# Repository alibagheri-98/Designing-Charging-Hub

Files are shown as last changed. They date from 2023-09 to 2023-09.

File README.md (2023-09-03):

During my 3-month internship at Nabz Company, I was tasked with creating a charging hub essential for Nabz's product lines. The development of this charging hub involved several phases:

## Phase 1: Literature Review
I commenced by conducting an extensive literature review of the ISO 13485 standard, utilizing research sources such as Research Gate, Scopus, and Google Scholar to gain comprehensive insights.
<br>
Screenshot (4620)
## Phase 2: Transformer Design
In the second phase, I employed the "PI Express" software to design the transformer. Subsequently, I thoroughly evaluated my design to ensure its suitability for the project. This included creating a schematic diagram, as shown in following image:
<br>
Screenshot (4622)
<br>
<br>
and an Altium Designer schematic diagram, as displayed in the following picture:
<br>
Screenshot (4624)
<br>
Screenshot (4626)

## Phase 3: Experimentation
Upon moving to the experimentation phase, an unexpected issue arose when the TNY280PN IC became excessively hot and ultimately failed within a few minutes. In response, we devised the idea of implementing a heat sink. This modification yielded excellent results, allowing the production line to begin using the charging hub successfully.

## Note:
- The report of my internship is in the "Report" folder.
- The simulations are in the "Simulation" folder.
- I received a "V_G" (Very Good) grade for my internship.
- My university supervisor for this internship was Dr. Zolghadri
- As per Sharif University of Technology's guidelines, internship reports should be in Persian. If you are interested in learning more about this project but are not proficient in Persian, please don't hesitate to reach out to me. We can arrange a meeting, and I will be happy to explain the project to you. You can contact me at [bagheri9877@gmail.com](bagheri9877@gmail.com).

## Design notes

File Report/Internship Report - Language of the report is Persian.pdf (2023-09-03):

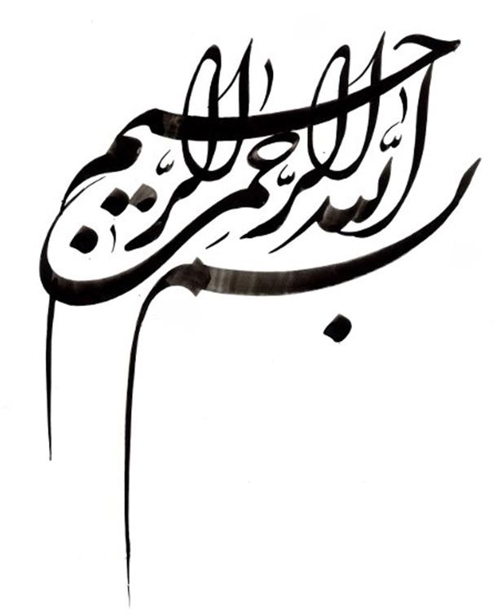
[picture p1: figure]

أ

أ

## دانشگاه صنعتی شریف

دانشکده مهندسی برق

گزارش کارآموزی
گرایش سیستم های انرژی الکتریکی

عنوان:

## گزارش کارآموزی در شرکت نبض هوشمند سالمت

نگارش :
علی باقری
96101302

استاد کارآموزی :
جناب آقای دکتر ذوالقدری

تاریخ)ماه و سال( : 1400/06

چکیده

تابستان سال 1400 فرصتی شد تا واحد کارآموزی را در شرکت نبض هوشمند سالمت به انجام برسانم.
در این گزارش ابتدا به معرفی شرکت و چگونگی سپری شدن این دوره 240 ساعته میپردازم و سپس پروژه واگذاری شده به من و فعالیت هایم را شرح میدهیم. در ابتدا در طی جلساتی توضیحات و روال کارآموزی داده شد و به تیم سازی پرداختیم. همچنین مدتی را به یادگیری کلیات کارآموزی پرداختیم. سپس به کارآموزان پروژه هایی واگذار شد که در این دوره روی آن پروژه ها کار کردند.

در پروژه ای که به ما واگذار شده بود، هدف طراحی یک هاب شارژر با ورودی برق شهر، و چهار خروجی USB بود. در ابتدا به مروری بر ادبیات پرداختیم و مقاالت مرتبط و منابع آموزشی علمی را به سرپرستی آقای محمد سعید دیاری بررسی کردیم. سپس یک طراحی اولیه انجام دادیم و بعد از شبیه سازی، به نمونه سازی رسیدیم. البته در فاز نمونه سازی مهلت کاراموزی تمام شد و پروژه در این مرحله تحویل شرکت گردید.

در فصل اول تاریخچه ای از شرکت را بیان میکنیم و در مورد فعالیت های صنعتی این شرکت توضیح میدهیم. سپس در فصل بعدی از فعالیت خودم در این دوره 240 ساعته میگوییم و در نهایت در فصل بعدی نتایج را بررسی میکنیم. امیدوارم این گزازش مورد قبول شما باشد.

توجه: شرکت نبض هوشمند سالمت، تاکید کرد که اطالعات گردآوری شده در این گزارش کارآموزی در جنبه های تجاری و رقابتی استفاده نگردد.

فهرست

1 فصل اول: آشنایی با شرکت نبض هوشمند سالمت 6 |
1-1 معرفی شرکت 6 |
1-2 چارت سازمانی شرکت 7 |
1-3 آینده شرکت نبض هوشمند سالمت 8 |

فهرست شکل ها

شکل :1-1 سه راهی تجاری برند تیراژه با دو درگاه USB | 10
شکل :2-1 شماتیک مدار ترانس | 11
شکل :3-1 برد طراحی شده شماتیک مدار ترانس | 12
شکل :4-1 برد طراحی شده شماتیک مدار ترانس | 13

### 1 فصل اول: آشنایی با شرکت نبض هوشمند سالمت

معرفی شرکت

گروه نبض در سال 1395 به صورت یک تیم کوچک فعالیت خود را در زمینه ی

ساخت تجهیزات توان بخشی شروع کرد. از تابستان سال 1396 توجه و تمرکز خود را به

زمینه تولید تجهیزات نوین پزشکی معطوف کرد. امروز فعالیت شرکت حول طراحی و تولید

ابزار ها و تجهیزات پیشرفته حوزه ی سالمت میگردد. هدف اصلی شرکت نبض هوشمند

سالمت، همراهی با مردم و پزشکان در راستای ارتقای سطح سالمت و گسترش خدمات

پزشکی است.

شرکت نبض هوشمند سالمت، با تولید ابزارها و گجتهای هوشمند حوزه سالمت در

تالش است تا از یک سو در کنار پزشکان و از سوی دیگر در کنار تمامی افرادی که به

سالمت جسمانی خود و عزیزانشان بها میدهند، قرار گیرد.

یکی از محورهای اصلی تفکرات شرکت نبض هوشمند سالمت، کمک گرفتن از

نیروهای جوان و با انگیزه در راستای استفاده از تکنولوژی و بهکارگیری خالقیت برای تولید

محصوالتی جدید است که نیازهایی واقعی را از مخاطب برطرف کنند. به دور از شعار، با

فعالیت ها و محصوالت خود طی سال های گذشته این شرکت سعی کرده است که نشان

دهد مصرانه به دنبال خلق دانش و ایجاد محصوالت با کیفیتی است تا مخاطب از کار کردن

با آن ها لذت ببرد.

از محورهای اصلی دیگر، امر تولید است؛ مسئلهای که شاید در شرایط کنونی کشور،

بسیاری از کارآفرینان بهناچار از آن فاصله گرفتهاند. مراحل طراحی محصول، فراهم آوردن

قطعات و ملزومات، مراحل تحقیق و توسعه، تست و عیبیابی و درنهایت اخذ تاییدیهها و

مجوزها و راهاندازی خط تولید از مواردی هستند که شاید به دلیل شرایط سختی که هرکدام

به همراه دارند، بسیاری را از ورود به مسیر تولید بازدارند. اما تمامی افراد حاضر در شرکت

نبض هوشمند سالمت، به دلیل ارزشی که در تولید هم برای سطح دانش و صنعت کشور و

هم برای چرخیدن چرخ اقتصاد و بهرهمند شدن تمام ایرانیان از برکات آن وجود دارد،

مصمم به ادامه این مسیر هستند و با وجود تمامی فشارها و سختیها، با امید فراوان به

آیندهای روشن تالش میکنند و از تمامی بازیگران این عرصه برای همکاری و توسعه این

مسیر در هر جایگاهی، استقبال میکنند.

چارت سازمانی شرکت

بخش مدیریت در باالترین سطح این شرکت قرار دارد و به سه قسمت -1تحقیق و

توسعه، -2نرم افزار و پلتفرم و -3 حقوقی و مالی تسلط دارد

واحد تحقیق و توسعه دارای زیر بخش های سخت افزار، واحد تولید، واحد کنترل

کیفیت است. همچنین واحد نرم افزار و پلتفرم دارای زیر بخش های نرم افزار، هوش

مصنوعی و یادگیری و پردازش سیگنال میباشد.

واحد حقوقی و مالی شامل بخش های فروش، پشتیبانی، مالی و حقوقی و انبار میباشد.

آینده شرکت نبض هوشمند سالمت

در حال حاضر و در شرایط فعلی که درگیر کرونا هستیم، شرکت نبض هوشمند سالمت

با رعایت کامل پروتکل های بهداشتی به فعالیت های خود ادامه میدهد تا برای عبور از این

شرایط سخت، تیم پزشکی را همراهی کند.

این شرکت در حال توسعه پروژه های سطح باال است تا در آینده شاهد توسعه گسترده

خویش باشد و همزمان با این مهم، یاری دهنده شرایط کشور در تحریم نیز باشد.

### 2 فصل دوم: یادگیری و پیاده سازی

مقدمه

موضوع دوره کاراموزی، طراحی و نمونه سازی یک دستگاه هاب شارژر بود که برای

خط تولید شرکت مورد نیاز است. بخشی از فرایند تولید و کنترل کیفی دستگاه های شرکت

نبض، شارژ باتری دستگاه هاست. با توجه به سیاست افزایش تیراژ تولید، نیاز به تعداد

بیشتری شارژر احساس شد بر همین مبنا، بجای خرید تعداد قابل توجهی شارژر، این راه

حل مطرح شد که صرفا کابل های شارژر خریداری شوند و جای قسمت به اصطالح آداپتور

شارژر، یک هاب طراحی شود که چندین خروجی داشته باشد.

از آنجایی که محصوالت شرکت دسته بندی های مختلفی دارند، تصمیم اولیه بر این

شد که هر هاب دو درگاه خروجی داشته باشد که دو درگاه آن 2 آمپر و 2 درگاه آن 1 آمپر

باشد. تعبیر فنی این اصطالح یعنی هر درگاه حداکثر تا چند آمپر را می تواند تامین کند.

مروری بر ادبیات

اولین موضوع مهم در پروژه های طراحی یک محصول، جمع آوری درست و علمی

دانش است. در این پروژه ما بر اساس استاندارد 13485ISO به مروری بر ادبیات پرداختیم.

بطور خالصه می توانیم بگوییم در سه مرحله کلی، مقاالت را غربال می کنیم. ابتدا در پایگاه

های داده مقاالت مانند gate Research ,Scopus ,scholar Google و سامانه های

داخلی مانند سیویلیکا، چند کلید واژه و عبارت مرتبط را انتخاب می کنیم و براساس نام

مقاالت آن ها را برمیگزینیم. سپس از بین مقاالت منتخب، براساس خالصه مقاالت تعدادی

دیگر را غربال می کنیم ودر نهایت به مطالعه متن کامل آن ها می پردازیم تا بتوانیم پارامترهای

موثر و سبک طراحی ادبیات رایج علمی در آن حوزه را کمی بشناسیم.

پس از پایان فاز مطالعه به یک نمونه مشابه تجاری )با قابلیت های کمتر( خریداری

کردیم و به مهندسی معکوس و استخراج نقشه فنی آن پرداختیم. محصول مذکور، یک سه

راهی تجاری برند تیراژه با دو درگاه USB است که در تصویر زیر آن را مشاهده می کنیم.

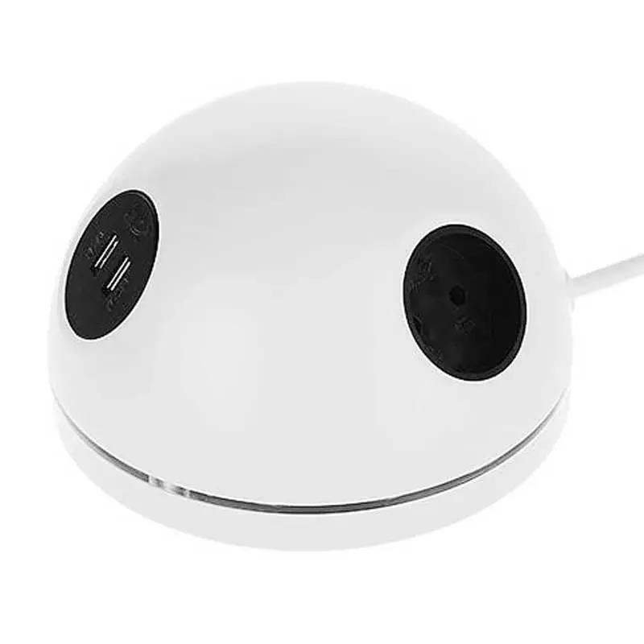
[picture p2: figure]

در فاز بعدی به طراحی ترانس توسط نرم افزار Express PI پرداختیم. نمونه ترانس

را برای ساخت سفارش دادیم و بر روی مدارهای آزمایشی )به اصطالح هزارسوراخ( مدرا

را امتحان کردیم.

شماتیک مدار طراحی شده را در شکل زیر می بینم:

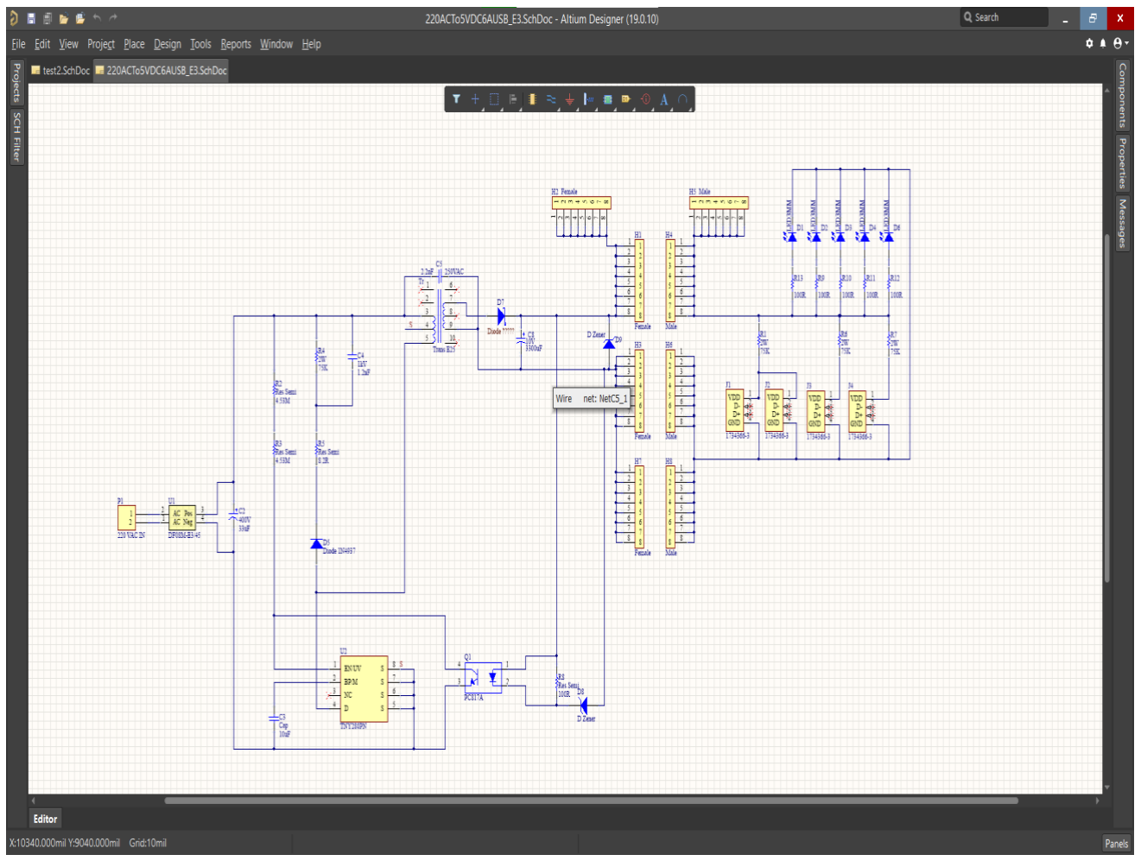
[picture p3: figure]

در آزمایش این مدار، آی سی PN280TNY بسیار داغ می شد و پس از چند دقیقه

کامال می سوخت. بخش قابل توجهی از زمان سپری شده، به رفع این عیب اختصاص داد

شد. پس از چند روز به این مورد احتمال داده شد که ترانس به اشتباه پیچیده شده باش و

مطابق با نقشه فنی مورد نظر ما نباشید. در حقیقت دراثر اشتباه سازنده، ترانس در مشخصات

درستی کار نکند. سفارش دوباره ترانس و مذاکره با ارائه دهنده خدمات پیچیدن ترانس، در

کنار زمان بر بودن این امر، بخش زیادی از زمان پروژه را طی کرد.

برای استفاده درست از زمان، به یادگیری طراحی PCB در نرم افزار Altium

Designer در این زمان پرداختیم. برد طراحی شده شماتیک باال را در تصویر زیر مشاهده

می کنیم:

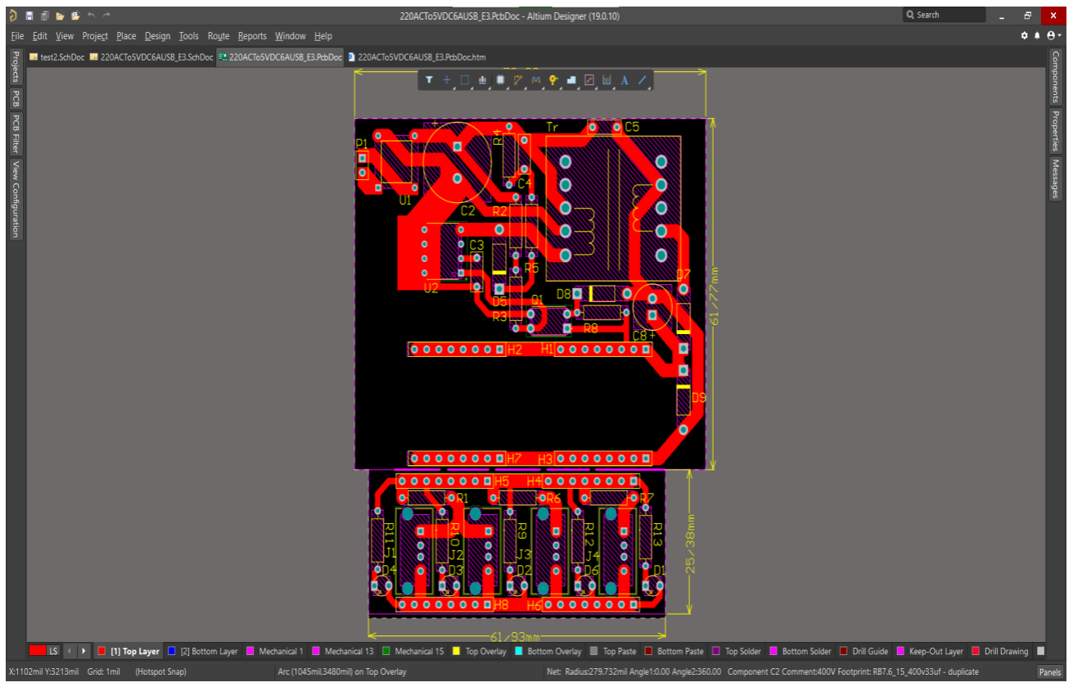
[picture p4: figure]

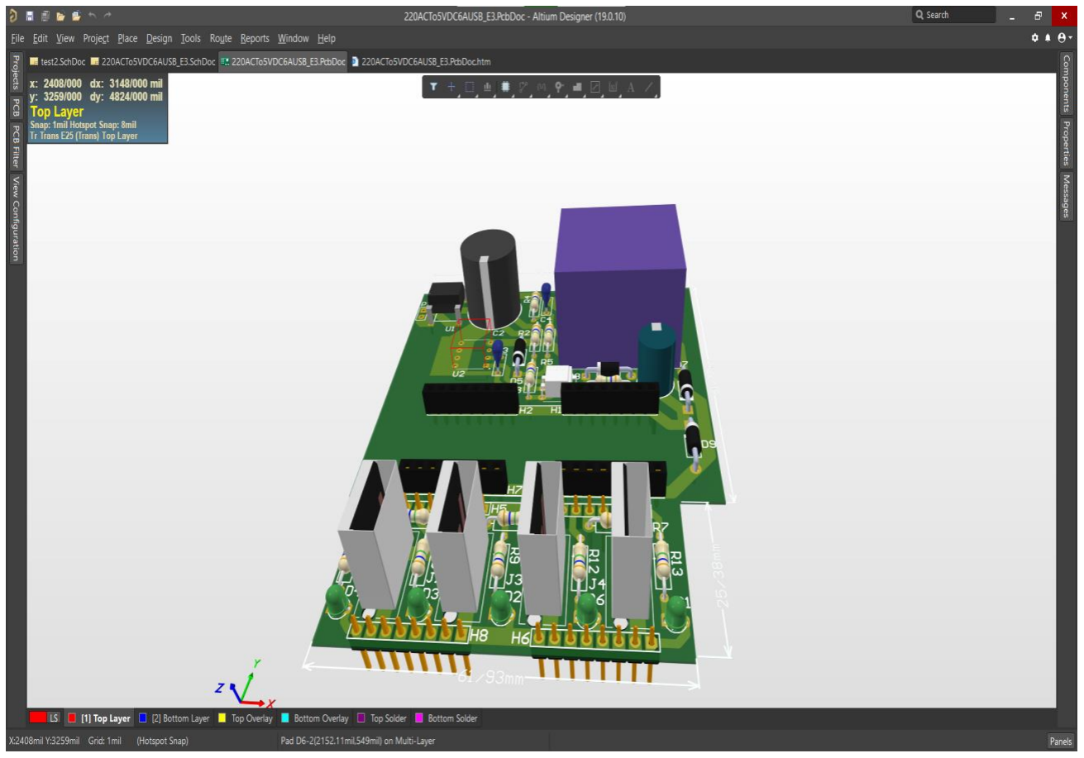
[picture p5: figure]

دراین طراحی، مالحظات جریان باال و حرارت در طراحی مدنظر قرار گرفته است.

پس از آزمایش مجدد متوجه شدیم مجددا در اثر اشتباه سازنده، ترانس را برای آی سی

های switch Top پیچیده اند و سازگار با آی سی های Switch Tiny نیست. بنابراین

مجددا پیگیر یک نمونه ترانس جدید شدیم.

اما در کمال تعجب پس از آزمایش ترانس جدید مشاهده کردیم که بازهم آی سی

PN280TNY داغ می شود و درنهایت پس از مدت کوتاه چند دقیقه ای می سوزد. در

نهایت پس از پرس و جو متوجه شدیم با استفاده از ابزارهای خنک کننده مانند Heat

Sink می توانیم دمای این آی سی را کنترل کنیم و مدار توانست در حالت پایدار خود

بماند.

متاسفانه بعلت زمان بر بودن فرایند هایی مانند پیچیدن ترانس، این پروژه تا همین نقطه

پیشرئی داشت و به پایان رساندن آن نیازمند زمان بیشتری ست.

### 3 فصل سوم: جمعبندی، نتیجهگیری و پیشنهادها

جمعبندی

بطور خالصه ما ابتدا با تجهیزات و محصوالت شرکت آشنا شدیم و سپس شروع به

ساخت پروژه بخش خود، یعنی دستگاه هاب شارژر، کردیم. برای این کار ابتدا به جمع

آوری اطالعات پرداختیم و نمونه خارجی مشابه را بررسی کردیم. با بررسی آن توانستیم

نقشه فنی اش را مهندسی معکوس کنیم. برای این کار نیاز داشتیم نرم افزار های مرتبط با

این حوزه را نیز یاد بگیریم. برای همین نرم افزار Designer Altium، نرم افزار

Proteus و نرم افزار Express PI را یاد گرفتیم. سپس با توجه به نقشه فنی ای که بدست

آوردیم ترانس را طراحی کردیم.

در آزمایش مداری که بستیم چون آی سی PN280TNY داغ میشد به رفع عیب آن

پرداختیم. برای این اتفاق احتماالت مختلفی مطرح شد مثال در یک مورد احتمال دادیم ایراد

به دلیل که شاید ترانس اشتباه پیچیده شده است. در نهایت مشکل را حل کردیم و با کمک

خنک کننده Sink Heat این مشکل به طور کامل برطرف شد و مدار توانست به حالت

پایدار خود برسد.

نتیجهگیری

نتیجه بسیار مهمی که از این پیاده سازی گرفتیم این است که برای مهندسی معکوس

کردن نیاز نیست دقیقا نمونه خارجی را کپی کنیم و میتوانیم با خالقیت خود آنرا بهبود

بدهیم. مثال در این پروژه از Sink Heat استفاده کردیم که نمونه خارجی اش دقیقا این

مورد را نداشت. همچنین استفاده از ایده های یک دیگر و کار تیمی میتواند باعث نتایج

بسیار خوبی بشود.

البته کارآموزی در این 240 ساعت به پایان رسید اما برای ادامه مطالعات در این حوزه

و کسب دانش بیشتر از مهر ماه نیز در این شرکت فعالیت میکنم تا به نتایج بهتری برسیم و

حتی در صورت امکان نمونه تجاری را نیز وارد بازار کنیم.

پیشنهادها

به دلیل پیگیری مناسب مسئولین شرکت، دادن پروژه های بسیار خوب و جو صمیمی

شرکت و همچنین وجود جلسات متعدد، همه مراحل کارآموزی بسیار عالی سپری شد و

برای همین انتقادی نسبت به روند کارآموزی ندارم و پیشنهاد میکنم برای کارآموزی های

بعدی نیز سیستم مناسب و آموزنده را در پیش بگیرند.

از موارد خوبی که این شرکت را نسبت به برخی از شرکت ها متمایز میکند این است

که شرایط بازدید حضوری را فراهم میکنند و در فعالیت بصورت حضوری تمام پروتکل ها

با دقت کامل رعایت میشود. همچنین تهویه موجود در شرکت نیز بسیار خوب است که

باعث میشود از دغدغه کرونا فاصله بگیریم و با تمرکز کامل وظایف محول شده در

کارآموزی را انجام دهیم.

مراجع

[1] K. N. Mude, “Battery Charging Method for Electric Vehicles: From

Wired to On-Road Wireless Charging,” Chinese Journal of Electrical

Engineering, Vol.4, No.4, December 2018

[2] N. Bodo, E. Levi, “Efficiency Evaluation of Fully Integrated On-Board

EV Battery Chargers with Nine-Phase Machines,” IEEE transaction on energy

conversion, Vol. 32, No. 1, March 2017

[3] E. D. Lierena, D. C. Guillen, “Versatile SoC architecture for

integration of HW accelerators in power electronics applications,” 2020 IEEE

International Conference on Industrial Technology (ICIT) 12 march 2020

[4] M. Nasr, K. Gupta “SiC based on-board EV power-hub with high-

efficiency DC transfer mode through AC port for vehicle-to-vehicle

charging,” 2018 IEEE Applied Power Electronics Conference and Exposition

(APEC), 19 April 2018
